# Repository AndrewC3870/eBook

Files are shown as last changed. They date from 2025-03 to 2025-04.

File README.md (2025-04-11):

# OpenBook
Fully functional E-book reader project!
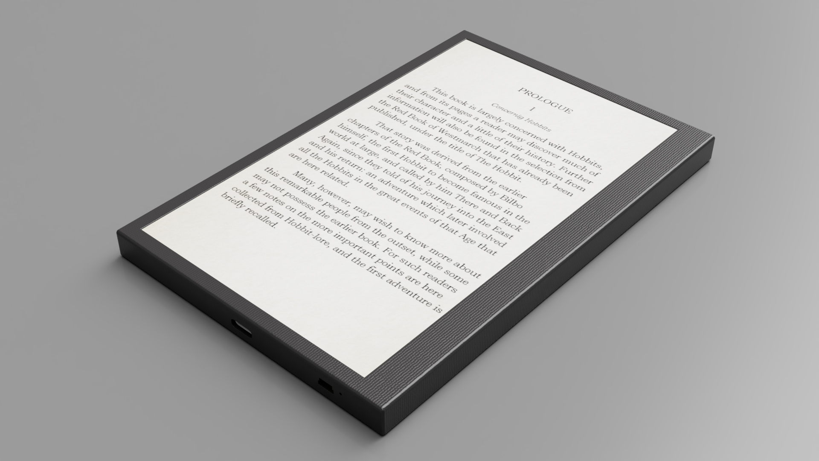
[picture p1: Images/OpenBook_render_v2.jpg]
OpenBook_render_img

## 🧾 Bill of Materials (BOM)

| Component | Link to buy | Datasheet |
|---|---|---|
|ESP32-C6 | [Mouser](https://ro.mouser.com/ProductDetail/Espressif-Systems/ESP32-C6-WROOM-1-N8?qs=8Wlm6%252BaMh8ST02Gmwp74cw%3D%3D) | [Datasheet](https://ro.mouser.com/datasheet/2/891/Espressif_ESP32_C6_WROOM_1__Datasheet_V0_1_PRELIMI-3239987.pdf)|
| E-Ink Display 7.5" 800x480 | [Waveshare](https://www.waveshare.com/7.5inch-e-paper.htm) | [Datasheet](https://files.waveshare.com/upload/6/60/7.5inch_e-Paper_V2_Specification.pdf) |
| SD Module | [Comet](https://store.comet.srl.ro/Catalogue/Product/43497/) | [Datasheet](https://store.comet.bg/download-file.php?id=8824)|
| Polymer Lithium-Ion Battery | [TME](https://www.tme.eu/en/details/accu-lp584174_cl/rechargeable-batteries/cellevia-batteries/l584174/) | [Datasheet](https://www.tme.eu/Document/e0683d8c34e6d878124489f71bffb6ee/cel0014.pdf)|
| RTC DS3231SN  | [Mouser](https://ro.mouser.com/ProductDetail/Analog-Devices-Maxim-Integrated/DS3231SN?qs=1eQvB6Dk1vhUlr8%2FOrV0Fw%3D%3D) | [Datasheet](https://ro.mouser.com/datasheet/2/609/DS3231-3421123.pdf)|
| Environmental Sensor BME688 | [Mouser](https://ro.mouser.com/ProductDetail/Bosch-Sensortec/BME688?qs=IS%252B4QmGtzzqQoVDscqwx3A%3D%3D) | [Datasheet](https://ro.mouser.com/datasheet/2/783/bst_bme688_fl000-2307034.pdf)|
| Li-Po Battery Charging Controller | [Mouser](https://ro.mouser.com/ProductDetail/Microchip-Technology/MCP73831T-3ACI-OT?qs=yUQqVecv4quInAWkk8YFWg%3D%3D) | [Datasheet](https://ro.mouser.com/datasheet/2/268/MCP73831_Family_Data_Sheet_DS20001984H-3441711.pdf)|
| LDO Regulator | [Mouser](https://ro.mouser.com/ProductDetail/Torex-Semiconductor/XC6220A331MR-G?qs=AsjdqWjXhJ8ZSWznL1J0gg%3D%3D) | [Datasheet](https://ro.mouser.com/datasheet/2/760/xc6220-3371556.pdf)|
| External NOR Flash (64MB) | [Mouser](https://ro.mouser.com/ProductDetail/Winbond/W25Q512JVEIQ?qs=l7cgNqFNU1jw6svr3at6tA%3D%3D) | [Datasheet](https://ro.mouser.com/datasheet/2/949/Winbond_W25Q512JV_Datasheet-3240039.pdf)|
| USB-C Connector | [Mouser](https://ro.mouser.com/ProductDetail/GCT/USB4110-GF-A?qs=KUoIvG%2F9IlYiZvIXQjyJeA%3D%3D) | [Datasheet](https://ro.mouser.com/datasheet/2/837/GCT_USB4110_Product_Drawing___20k_cycles-3455479.pdf)|
| Buttons (x3)  | [CoolBe](https://www.coolbe.ro/ro/products/5bad89f21436d4015a56b3cd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) | [Datasheet](https://www.coolbe.ro/ro/products/5bad89f21436d4015a56b3cd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)|
| Qwiic | [SPARKFUN](https://www.sparkfun.com/qwiic-jst-connector-smd-4-pin-horizontal.html) | [Datasheet](https://cdn.sparkfun.com/assets/parts/1/2/2/8/9/Qwiic_Connector_Datasheet.pdf)|
| Schottky Diodes | [Mouser](https://ro.mouser.com/ProductDetail/KYOCERA-AVX/SD0805S020S1R0?qs=jCA%252BPfw4LHbpkAoSnwrdjw%3D%3D) | [Datasheet](https://ro.mouser.com/datasheet/2/40/schottky-3165252.pdf)|
|Resistors | [Mouser](https://ro.mouser.com/c/?q=resistor%200402) | [Datasheet](https://ro.mouser.com/c/?q=resistor%200402)|
|USBLC6-2SC6Y | [Digikey](https://www.digikey.ro/ro/products/detail/stmicroelectronics/USBLC6-2SC6Y/2819177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) | [Datasheet](https://www.st.com/content/ccc/resource/technical/document/datasheet/group0/94/15/6c/58/ba/91/46/42/DM00055262/files/DM00055262.pdf/jcr:content/translations/en.DM000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)|
|Transistors | [Mouser](https://ro.mouser.com/ProductDetail/Diodes-Incorporated/DMG2305UX-7?qs=L1DZKBg7t5F%2FNBHrjfxC%252Bg%3D%3D) | [Datasheet](https://www.diodes.com/assets/Datasheets/DMG2305UX.pdf)|
|SMC Diode | [DigiKey](https://www.digikey.ro/ro/products/detail/smc-diode-solutions/MBR0530/16692306) | [Datasheet](https://www.smc-diodes.com/propdf/MBR0530%20N0717%20REV.A.pdf)|
|N-channel MOSFET | [DigiKey](https://www.digikey.ro/ro/products/detail/vishay-siliconix/SI1308EDL-T1-GE3/4876435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) | [Datasheet](https://www.vishay.com/docs/63399/si1308edl.pdf)|
|Display Connector | [Mouser](https://ro.mouser.com/ProductDetail/Hirose-Connector/FH34SRJ-24S-0.5SH99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) | [Datasheet](https://ro.mouser.com/datasheet/2/185/FH34SRJ_24S_0_5SH_99__CL0580_1255_6_99_2DDrawing_0-1615044.pdf)|
|Power Inductor | [Mouser](https://ro.mouser.com/ProductDetail/Bourns/SRR4828A-101M?qs=EU6FO9ffTwcw5i9FweW3JA%3D%3D) | [Datasheet](https://ro.mouser.com/datasheet/2/54/srr4828a-1391533.pdf)|

## 📊 Bloc Diagram and PCB

<p align="center">
  
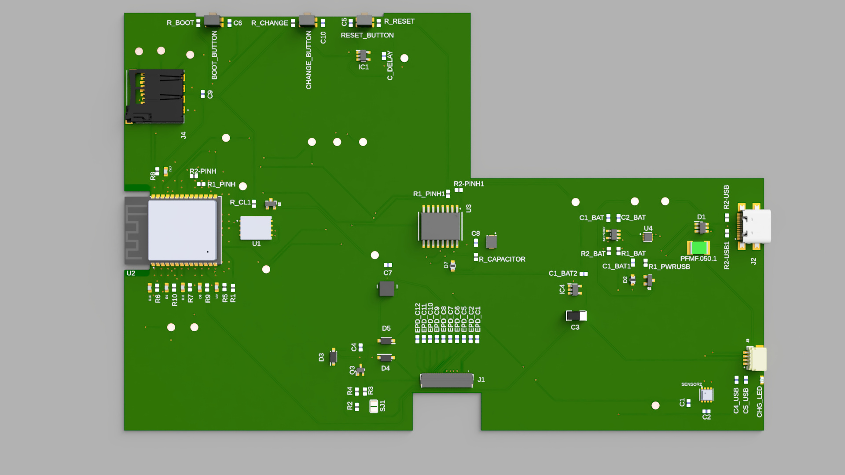
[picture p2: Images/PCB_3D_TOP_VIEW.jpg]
PCB
  
</p>

## 📗 Main Components and Connections
1. **Main processing unit**
    * `ESP32-C6 Microcontroller (ESP32-C6-WROOM-1-N8)` - The central processing unit of the system with WiFi/Bluetooth connectivity.

2. **Power Management System**
    * `LDO Voltage Regulator (XC6220A331MR-G)`: Provides stable 3.3V power from battery/USB

    * `Li-Po Battery Charging Controller (MCP73831)`: Manages charging of the LP584174 battery

    * `Battery Charge Level Monitoring (MAX17048G+T10)`: Connected via I2C to monitor battery status
3. **Display System**
    * `E-Ink Display (7.5" 800×480 px)`: Connected via SPI interface, displays the content

4. **Storage**
    * `External NOR Flash (W25Q512JVEIQ, 64MB)`: Connected via SPI, main memory 64 MB

    * `SD Card`: Connected via SPI, used for external memory extension for adding books

5. **Environmental Sensing**
    * `BME688 Environmental Sensor`: Connected via I2C used to detect a wide variety of volatile organic compounds

6. **Real-Time Clock**
    * `DS3231SN RTC Module`: Connected via I2C (same bus as BME688)measures and tracks time, often in hours, minutes, and seconds

7. **User Interface**
    * `Buttons`: 3x GPIO buttons (Reset, Change, Boot)

8. **Connectivity**
    * `USB-C Connector`: For power and programming
    * `Qwiic/Stemma QT Connector`: I2C expansion port

## 🛠️ ESP32-C6 Used pins

| PIN | Component | Signal Name | Notes|
|-----|---|---|---|
| 3V3 | LDO Voltage Regulator | 3V3 | Supply power |
| EN | Reset Button | RESET| Reset in case of error |
| IO0| RTC Module | INT_RTC | High precision real time clock chip|
| IO1| RTC Module | 32KHZ| High precision real time clock chip|
| IO2| External NOR Flash, SD Card | MISO| Master In Slave Out|
| IO3| E-Paper Display | EPD_BUSY||
| IO4| SD Card | SS_SD | Extern memory (Micro SD cards)|
| IO5| E-Paper Display| EPD_DC||
| IO6| External NOR Flash, SD Card, E-Paper Display| SCK| SCK is the clock line for SPI communication|
| IO7| External NOR Flash, SD Card, E-Paper Display| MOSI|  Master Out Slave In|
| IO9| Boot Button | IO/BOOT| Boot|
| IO10| E-Paper Display | EPD_CS| for E-Ink display|
| IO11| External NOR Flash | FLASH_CS| |
| IO12| ESD protection | USB_D-| Protection against electrostatic discharges |
| IO13| ESD protection | USB_D+| Protection against electrostatic discharges |
| IO14| Change Button | IO/CHANGE| |
| IO15| Test Pads| TX| Transmit data|
| IO16| Test Pads | RX| Receive data|
| IO17| RTC Module | RTC_RST| |
| IO18| Environmental Sensor | I2C_PW|  To detect a wide variety of volatile organic compounds|
| IO19| EPD Power | EPD_3V3_C| Electronic power design|
| IO20| RTC Module, Qwiic / Stemma QT, Battery ChargeLevel| SDA| Transmit data to or from target devices|
| IO21| Battery ChargeLevel, Environmental Sensor, RTC Module, Qwiic / Stemma QT| SCL| Used to synchronously clock data in or out of the target device|
| IO22| E-Paper Display| EPD_RST| |
| GND| Ground | GND | Connected to the main ground|

## 🔋 Power Consumption Considerations
The system is designed for low power operation, because the most power consuming components are the screen and the ESP32-C6.

* E-Ink Display: Only consumes power during updates about **0.3mW**
* ESP32-C6: Can enter deep sleep mode **26.85 μW** between operations and the average power consumption during active mode is **78.32 mW**
* Battery 3.7V 1800mAh that is **6.6W** of power

The avarage lifetime of device is about 14-17 days!

## 🔄 Important updates
∘ Updated the 3d model of the case, maked the design more comfortable by adding smooth edges and a nice texture for better grip, also modified the interior size of the case to perfectly fit the components inside! 

∘ I have added some necessary files (a picture showing the arrangement of the components in the case, and the F3Z file with the complete design).

∘ In the future, the implementation of software that will allow the use of the eBook is expected.

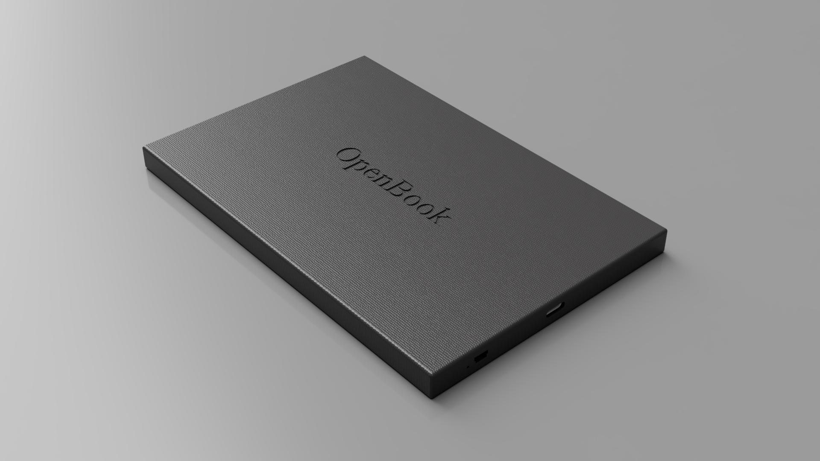
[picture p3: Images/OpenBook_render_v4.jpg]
OpenBook_render_img


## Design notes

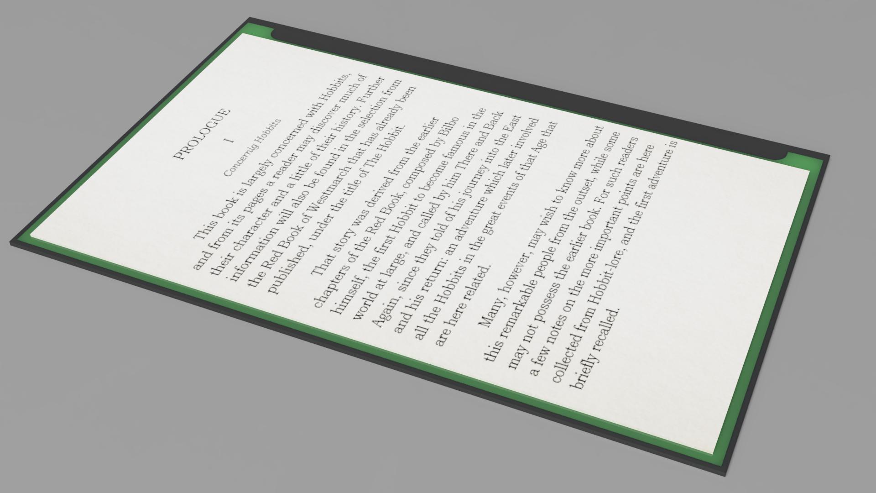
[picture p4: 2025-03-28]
Images/OpenBook_Display.jpg

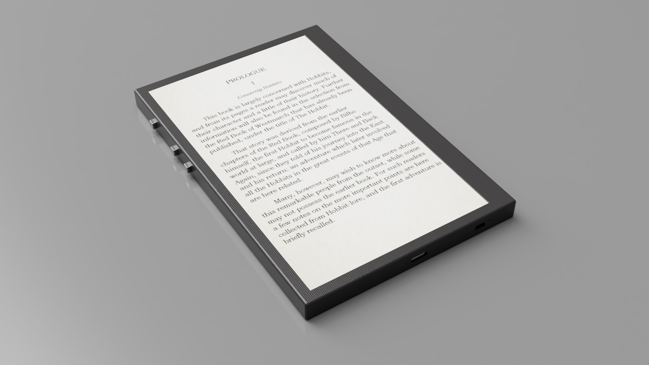
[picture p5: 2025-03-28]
Images/OpenBook_render_v1.jpg

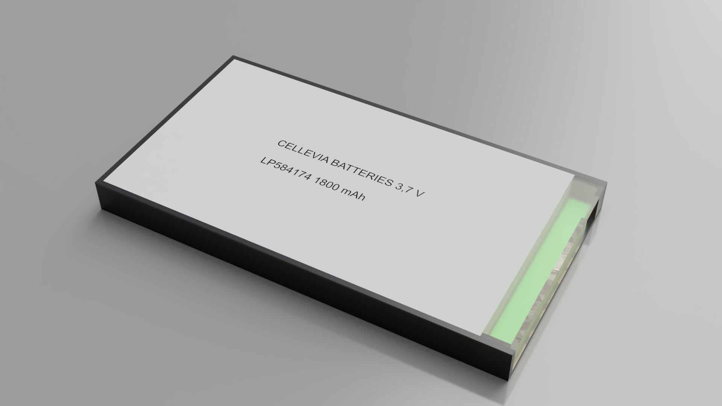
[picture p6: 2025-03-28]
Images/OpenBook_Battery.jpg

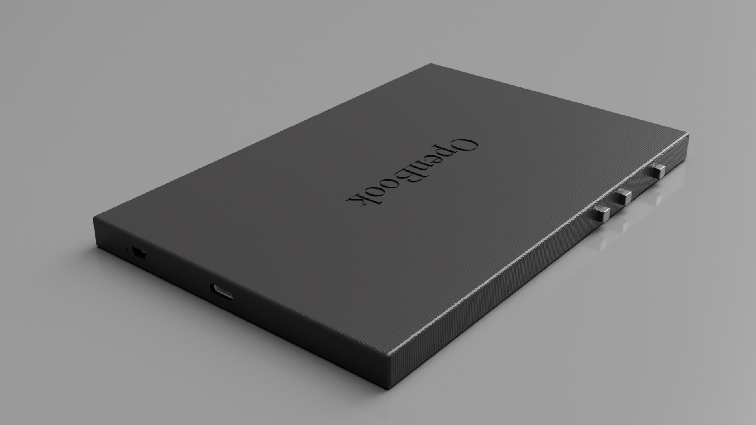
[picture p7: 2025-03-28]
Images/OpenBook_render_v3.jpg

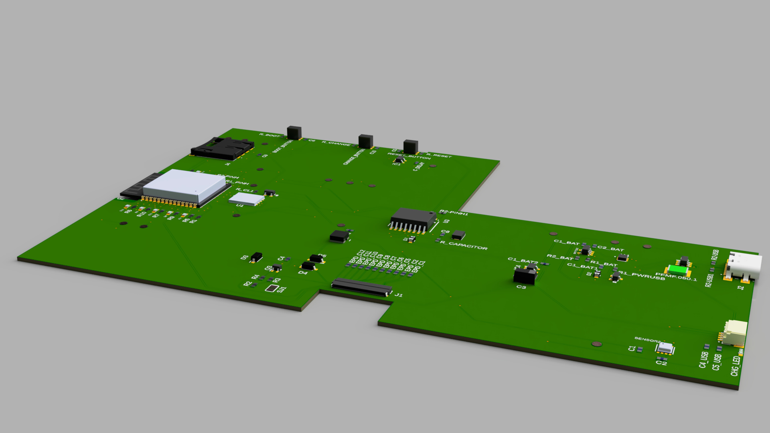
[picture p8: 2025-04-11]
Images/PCB_3D.jpg

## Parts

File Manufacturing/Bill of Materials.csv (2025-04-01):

Qty | Value | Device | Package | Parts | Description
1 |  | ADAFRUIT_LEDCHIP-LED0603 | ADAFRUIT_CHIP-LED0603 | CHG_LED | LED
1 |  | SJ | SJ | SJ1 | SMD solder JUMPER
1 | 0.47 | ESP32_WROVER_EAGLE-LTSPICE_RR0402 | ESP32_WROVER_EAGLE-LTSPICE_R0402 | R3 | RESISTOR, European symbol
1 | 100K | ESP32_WROVER_EAGLE-LTSPICE_RR0402 | ESP32_WROVER_EAGLE-LTSPICE_R0402 | R1_PWRUSB | RESISTOR, European symbol
8 | 100nF | EAGLE-LTSPICE_CC0402 | EAGLE-LTSPICE_C0402 | C1, C2, C4_USB, C6, C8, C9, C10, C_DELAY | CAPACITOR, European symbol
1 | 100uF TANT | RCL_CPOL-EUCT3528 | RCL_CT3528 | C3 | POLARIZED CAPACITOR, European symbol
16 | 10K | ESP32_WROVER_EAGLE-LTSPICE_RR0402 | ESP32_WROVER_EAGLE-LTSPICE_R0402 | R1, R1_PINH, R1_PINH1, R2-PINH, R2-PINH1, R4, R5, R6, R7, R8, R9, R10, R_BOOT, R_CHANGE, R_CL1, R_RESET | RESISTOR, European symbol
1 | 10uF | EAGLE-LTSPICE_CC0402 | EAGLE-LTSPICE_C0402 | C7 | CAPACITOR, European symbol
1 | 112A-TAAR-R03_ATTEND | 112A-TAAR-R03_ATTEND | 112ATAARR03ATTEND | J4 | Micro SD Card Socket, Push-Push Type, Top Mount, SMT, H=1.83mm, 10u
1 | 15 | ESP32_WROVER_EAGLE-LTSPICE_RR0402 | ESP32_WROVER_EAGLE-LTSPICE_R0402 | R_CAPACITOR | RESISTOR, European symbol
1 | 1uF | EAGLE-LTSPICE_CC0402 | EAGLE-LTSPICE_C0402 | C5 | CAPACITOR, European symbol
10 | 1uF/50V | EAGLE-LTSPICE_CC0402 | EAGLE-LTSPICE_C0402 | EPD_C1, EPD_C2, EPD_C5, EPD_C6, EPD_C7, EPD_C8, EPD_C9, EPD_C10, EPD_C11, EPD_C12 | CAPACITOR, European symbol
1 | 2.2 | ESP32_WROVER_EAGLE-LTSPICE_RR0402 | ESP32_WROVER_EAGLE-LTSPICE_R0402 | R2 | RESISTOR, European symbol
1 | 200 | ESP32_WROVER_EAGLE-LTSPICE_RR0402 | ESP32_WROVER_EAGLE-LTSPICE_R0402 | R1_BAT | RESISTOR, European symbol
2 | 20V/4.2A/52mO/1.4W | ESP32_WROVER_SPARKFUN-DISCRETESEMI_MOSFET_PCH-DMG2305UX-7 | ESP32_WROVER_SPARKFUN-DISCRETESEMI_SOT23-3 | Q1, Q2 | P-channel MOSFETs
1 | 2k | ESP32_WROVER_EAGLE-LTSPICE_RR0402 | ESP32_WROVER_EAGLE-LTSPICE_R0402 | R2_BAT | RESISTOR, European symbol
5 | 4.7uF | EAGLE-LTSPICE_CC0402 | EAGLE-LTSPICE_C0402 | C1_BAT, C1_BAT1, C1_BAT2, C2_BAT, C5_USB | CAPACITOR, European symbol
1 | 4.7uF/25V | EAGLE-LTSPICE_CC0402 | EAGLE-LTSPICE_C0402 | C4 | CAPACITOR, European symbol
2 | 5k1 | ESP32_WROVER_EAGLE-LTSPICE_RR0402 | ESP32_WROVER_EAGLE-LTSPICE_R0402 | R2-USB, R2-USB1 | RESISTOR, European symbol
1 | 744043680IND_4828-WE-TPC_WRE | 744043680IND_4828-WE-TPC_WRE | IND_4828-WE-TPC_WRE | L1
1 | BD5229G-TR | BD5229G-TR | SOT95P280X125-5N | IC1 | Voltage Detector with Adjustable Delay Time: CMOS processes are utilized to develop high precision, low current consumption CMOS reset ICs that allow arbitrary setting of the delay time. The extensive lineup includes both Nch Open Drain and CMOS output types in a wide range of detection voltages (from 2.3V to 6.0V, in 0.1V steps), enabling selection of the ideal solution based on customer requirements. In addition, the entire series is of course both lead-free and RoHS-compliant.
3 | BUTTON_CUSYOMV1 | BUTTON_CUSYOMV1 | MYBUTTON | BOOT_BUTTON, CHANGE_BUTTON, RESET_BUTTON
1 | CPH3225A | CPH3225A | CAPCP3225X100N | C10_SUPERCAP | Cap 0.011F 3.3V 1210 Flat Check availability
1 | DS3231SN# | DS3231SN# | SOIC127P1032X265-16N | U3 | Real Time Clock Serial 16-Pin SOIC W T/R Check availability
1 | ESP32-C6-WROOM-1-N8 | ESP32-C6-WROOM-1-N8 | XCVR_ESP32-C6-WROOM-1-N8 | U2 | Check availability
1 | ESP32C6_VARISTORCN1812 | ESP32C6_VARISTORCN1813 | ESP32C6_VARISTOR_CT/CN1812 | PFMF.050.1 | VARISTOR
2 | ESP32_WROVER_AVX---SD0805S020S1R0_AVX_SD0805S020S1R0_0_0AVX_SD0805S020S1R0_0_0 | ESP32_WROVER_AVX---SD0805S020S1R0_AVX_SD0805S020S1R0_0_0AVX_SD0805S020S1R0_0_0 | ESP32_WROVER_AVX---SD0805S020S1R0_AVX_SD0805S020S1R0_0 | D2, D7 | Schottky Barrier Rectifier Diode
1 | ESP32_WROVER_BME680_BME680 | ESP32_WROVER_BME680_BME680 | ESP32_WROVER_BME680_PSON80P300X300X100-8N | SENSOR2 | Integrated Environmental Unit
1 | ESP32_WROVER_SPARKFUN-IC-POWER_MCP73831 | ESP32_WROVER_SPARKFUN-IC-POWER_MCP73831 | ESP32_WROVER_SPARKFUN-IC-POWER_SOT23-5 | MCP73831 | MCP73831T Li-Ion, Li-Pol Controller
1 | FH34SRJ-24S-0.5SH_99_ | FH34SRJ-24S-0.5SH_99_ | FH34SRJ24S05SH99 | J1 | (0.50mm) Surface Mount, Right Angle
1 | MAX17048G+T10 | MAX17048G+T10 | SON50P200X200X80-9N | U4 | Check availability
3 | MBR0530 | MBR0530 | SOD3716X135N | D3, D4, D5 | ON SEMICONDUCTOR - MBR0530 - DIODE, SCHOTTKY, 0.5A, 30V, SOD-123
6 | PGB1010603MR | PGB1010603MR | DIOC1608X36N | D6, D8, D9, D10, D11, D12 | Check availability
1 | QWIIC_RIGHT_ANGLE | QWIIC_CONNECTORJS-1MM | JST04_1MM_RA | J3 | SparkFun I2C Standard Qwiic Connector
1 | SAMACSYS_PARTS_USB4110-GF-A | SAMACSYS_PARTS_USB4110-GF-A | SAMACSYS_PARTS_USB4110GFA | J2 | CONN USB 2.0 TYPE-C R/A SMT
1 | SI1308EDL-T1-GE3 | SI1308EDL-T1-GE3 | SOT65P210X110-3N | Q3 | MOSFET N-Ch 30V 1.5A TrenchFET SC70 Vishay Si1308EDL-T1-GE3 N-channel MOSFET Transistor, 1.5 A, 30 V, 3-Pin SC-70
17 | TPTP20R | TPTP20R | TP20R | TP1, TP2, TP3, TP4, TP5, TP6, TP7, TP8, TP9, TP10, TP11, TP12, TP13, TP14, TP15, TP16, TP17 | Test pad
1 | USBLC6-2SC6Y | USBLC6-2SC6Y | SOT95P280X145-6N | D1 | Low Cap. ESD Protection Auto SOT-23-6 STMicroelectronics USBLC6-2SC6Y, Dual Uni-Directional TVS Diode Array, 6-Pin SOT-23
1 | W25Q512JVEIQ | W25Q512JVEIQ | SON127P600X800X80-9N | U1 | Check availability
1 | XC6220A331MR-G | XC6220A331MR-G | SOT95P280X120-5N | IC4 | LDO Voltage Regulators

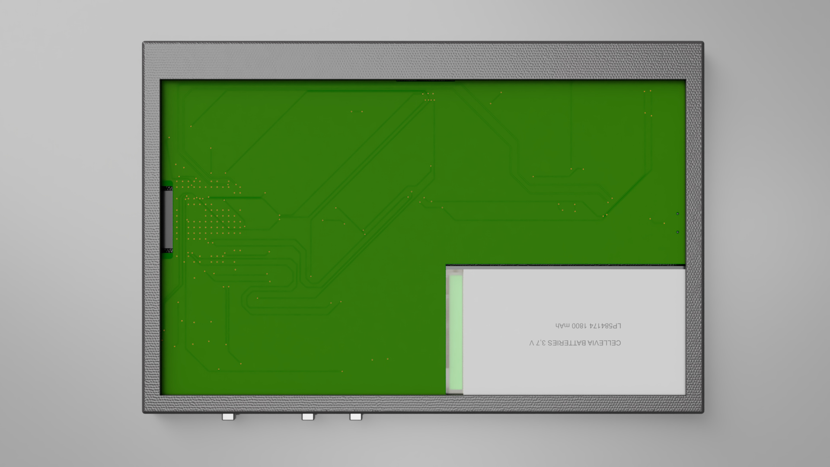
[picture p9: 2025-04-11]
Images/Component_positions.jpg

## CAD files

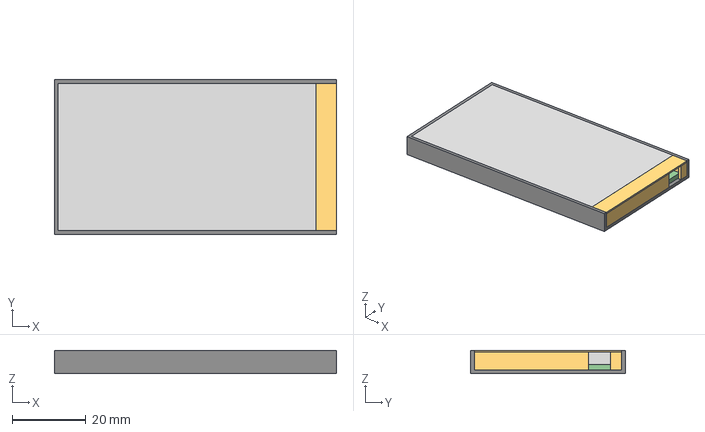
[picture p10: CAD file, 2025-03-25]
Mechanical/Battery_3D v1.step
76.5 x 42.0 x 6.30 mm

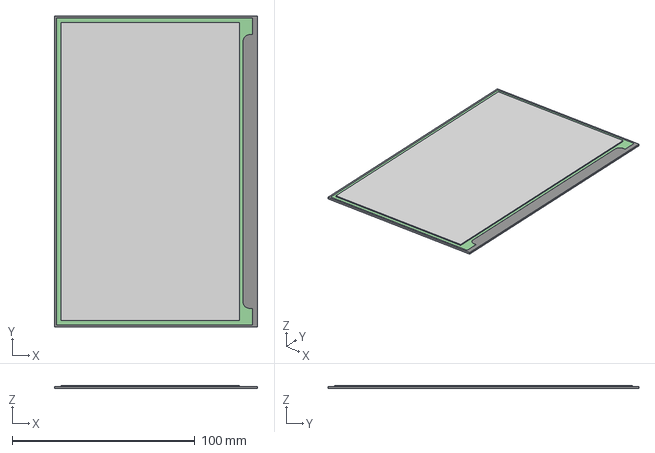
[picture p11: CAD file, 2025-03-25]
Mechanical/E-INK_screen_3D v3.step
111.2 x 170.2 x 1.88 mm

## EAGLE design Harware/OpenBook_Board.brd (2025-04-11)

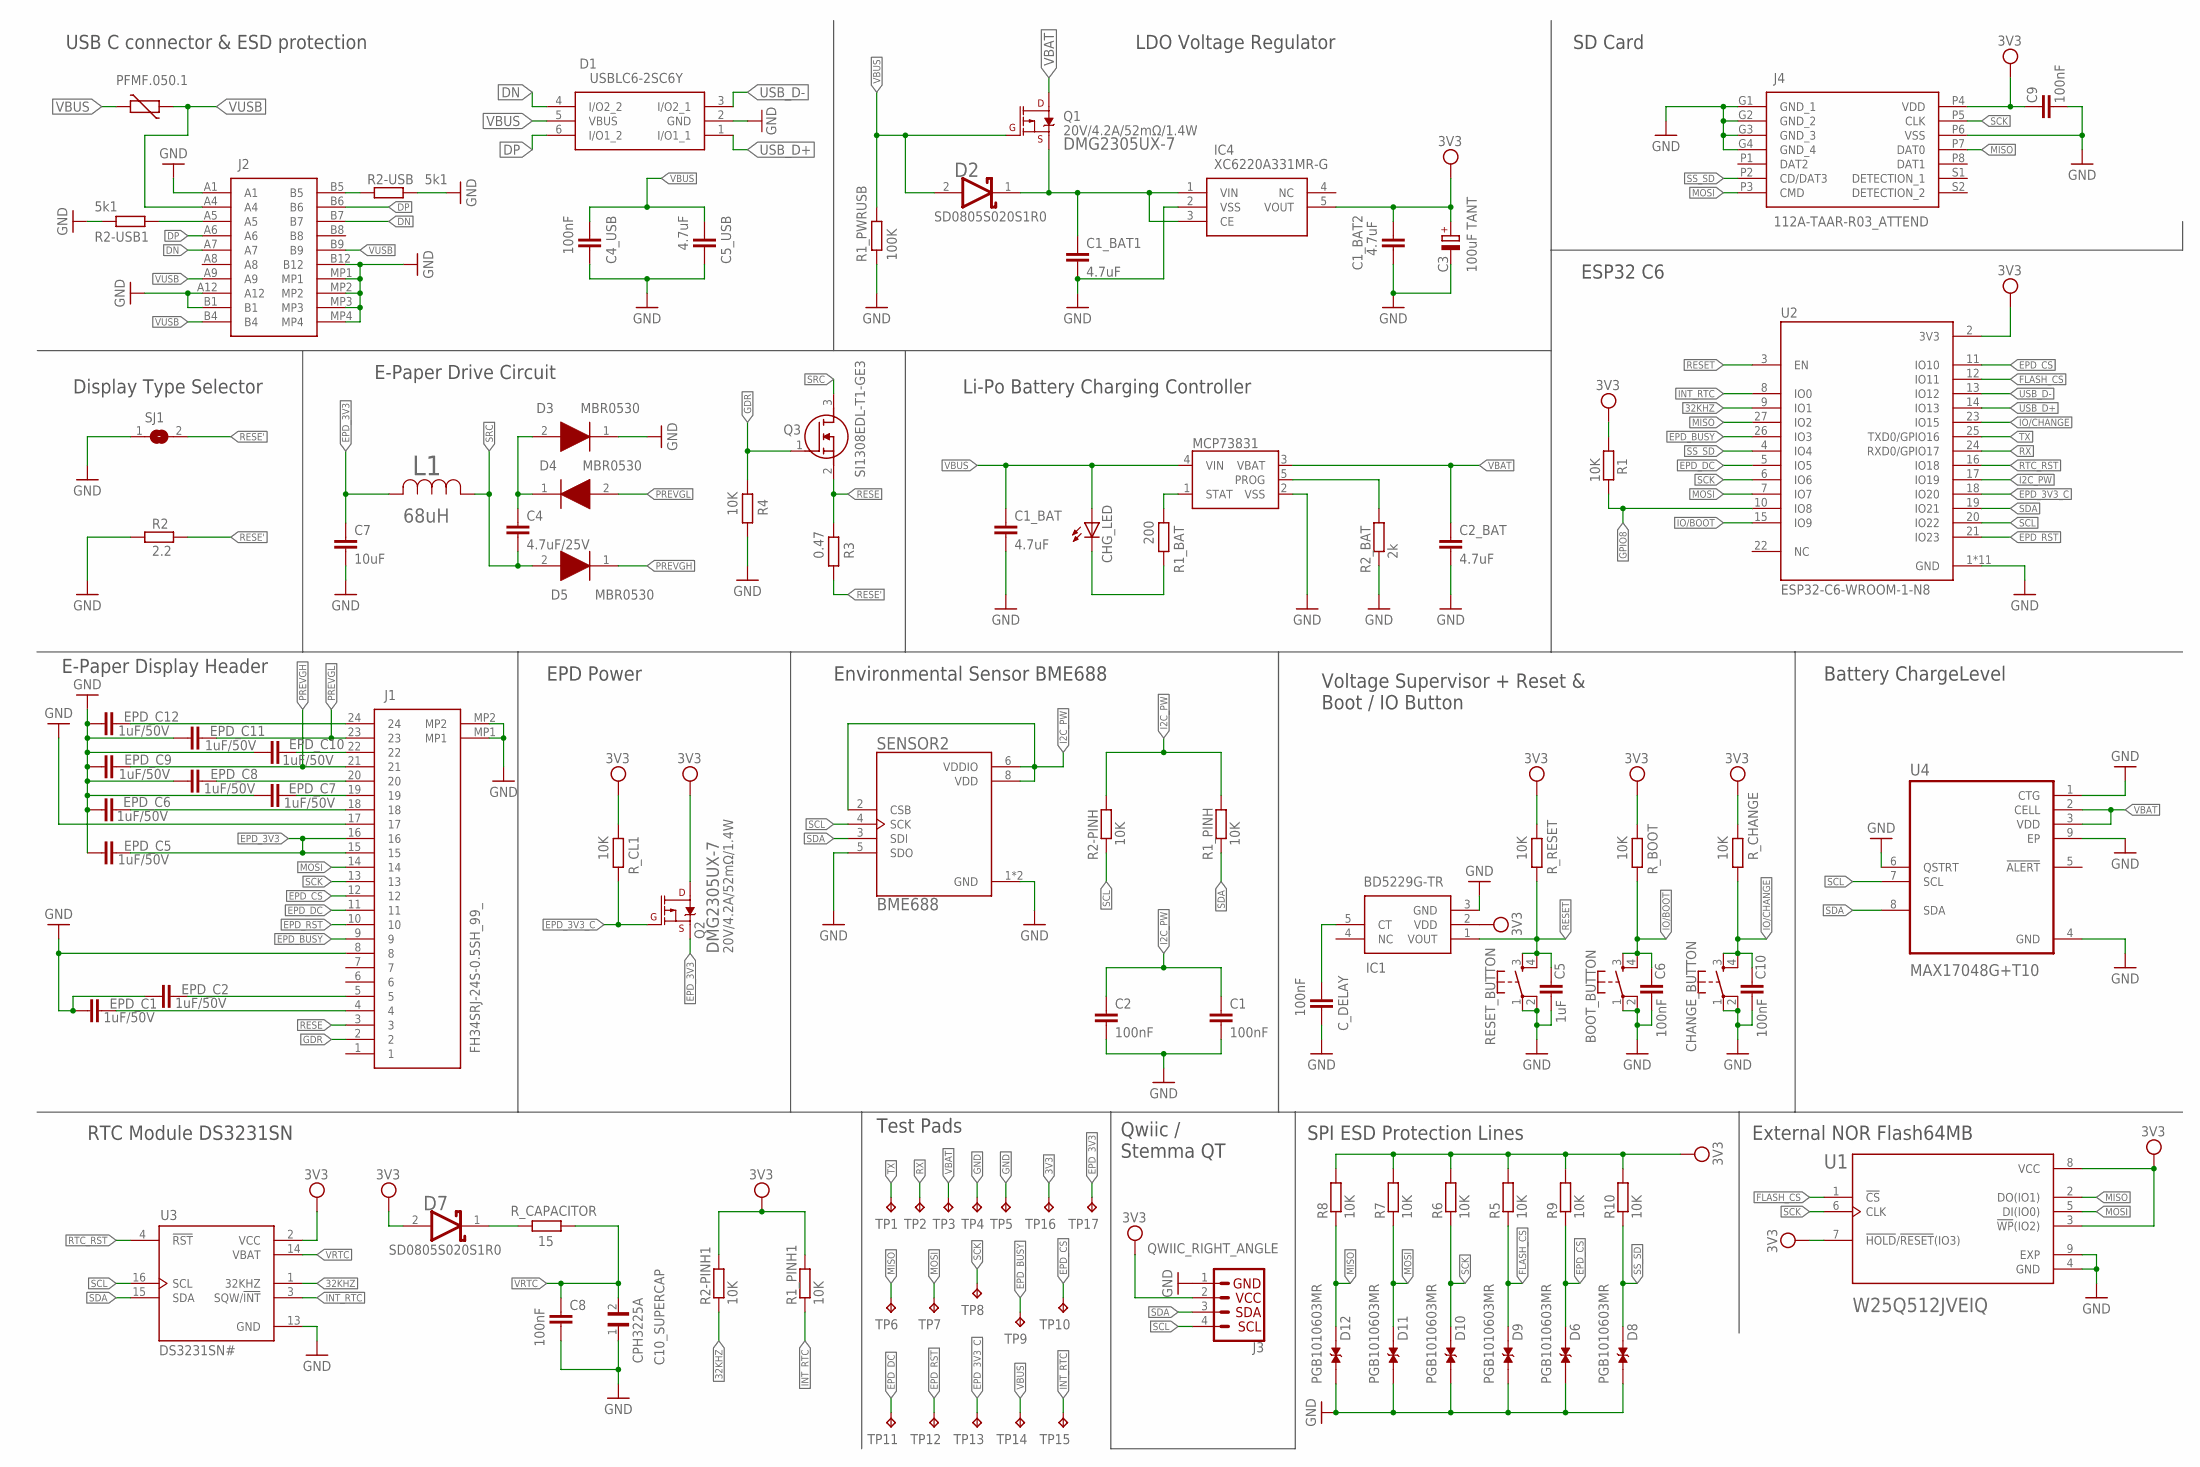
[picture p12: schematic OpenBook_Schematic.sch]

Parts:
BOOT_BUTTON: BUTTON_CUSYOMV1; MYBUTTON
C1, C2, C4_USB, C6, C8, C9, C10: 100nF; EAGLE-LTSPICE_C0402
C1_BAT, C1_BAT1, C1_BAT2, C2_BAT, C5_USB: 4.7uF; EAGLE-LTSPICE_C0402
C3: 100uF TANT; RCL_CT3528
C4: 4.7uF/25V; EAGLE-LTSPICE_C0402
C5: 1uF; EAGLE-LTSPICE_C0402
C7: 10uF; EAGLE-LTSPICE_C0402
C10_SUPERCAP: CPH3225A; CAPCP3225X100N
CHANGE_BUTTON: BUTTON_CUSYOMV1; MYBUTTON
CHG_LED: ADAFRUIT_LEDCHIP-LED0603; ADAFRUIT_CHIP-LED0603
C_DELAY: 100nF; EAGLE-LTSPICE_C0402
D1: USBLC6-2SC6Y; SOT95P280X145-6N
D2, D7: ESP32_WROVER_AVX---SD0805S020S1R0_AVX_SD0805S020S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; ESP32_WROVER_AVX---SD0805S020S1R0_AVX_SD0805S020S1R0_0
D3, D4, D5: MBR0530; SOD3716X135N
D6, D8, D9, D10, D11, D12: PGB1010603MR; DIOC1608X36N
EPD_C1, EPD_C2, EPD_C5, EPD_C6, EPD_C7, EPD_C8, EPD_C9, EPD_C10, EPD_C11, EPD_C12: 1uF/50V; EAGLE-LTSPICE_C0402
IC1: BD5229G-TR; SOT95P280X125-5N
IC4: XC6220A331MR-G; SOT95P280X120-5N
J1: FH34SRJ-24S-0.5SH_99_; FH34SRJ24S05SH99
J2: SAMACSYS_PARTS_USB4110-GF-A; SAMACSYS_PARTS_USB4110GFA
J3: QWIIC_RIGHT_ANGLE; JST04_1MM_RA
J4: 112A-TAAR-R03_ATTEND; 112ATAARR03ATTEND
L1: 744043680IND_4828-WE-TPC_WRE; IND_4828-WE-TPC_WRE
MCP73831: ESP32_WROVER_SPARKFUN-IC-POWER_MCP73831; ESP32_WROVER_SPARKFUN-IC-POWER_SOT23-5
PFMF.050.1: ESP32C6_VARISTORCN1812; ESP32C6_VARISTOR_CT/CN1812
Q1, Q2: 20V/4.2A/52mΩ/1.4W; ESP32_WROVER_SPARKFUN-DISCRETESEMI_SOT23-3
Q3: SI1308EDL-T1-GE3; SOT65P210X110-3N
R1, R1_PINH, R1_PINH1, R2-PINH, R2-PINH1, R4, R5, R6, R7, R8, R9, R10: 10K; ESP32_WROVER_EAGLE-LTSPICE_R0402
R1_BAT: 200; ESP32_WROVER_EAGLE-LTSPICE_R0402
R1_PWRUSB: 100K; ESP32_WROVER_EAGLE-LTSPICE_R0402
R2: 2.2; ESP32_WROVER_EAGLE-LTSPICE_R0402
R2-USB, R2-USB1: 5k1; ESP32_WROVER_EAGLE-LTSPICE_R0402
R2_BAT: 2k; ESP32_WROVER_EAGLE-LTSPICE_R0402
R3: 0.47; ESP32_WROVER_EAGLE-LTSPICE_R0402
RESET_BUTTON: BUTTON_CUSYOMV1; MYBUTTON
R_BOOT: 10K; ESP32_WROVER_EAGLE-LTSPICE_R0402
R_CAPACITOR: 15; ESP32_WROVER_EAGLE-LTSPICE_R0402
R_CHANGE: 10K; ESP32_WROVER_EAGLE-LTSPICE_R0402
R_CL1: 10K; ESP32_WROVER_EAGLE-LTSPICE_R0402
R_RESET: 10K; ESP32_WROVER_EAGLE-LTSPICE_R0402
SENSOR2: ESP32_WROVER_BME680_BME680; ESP32_WROVER_BME680_PSON80P300X300X100-8N
SJ1: SJ
TP1, TP2, TP3, TP4, TP5, TP6, TP7, TP8, TP9, TP10, TP11, TP12, TP13, TP14, TP15, TP16, TP17: TPTP20R; TP20R
U1: W25Q512JVEIQ; SON127P600X800X80-9N
U2: ESP32-C6-WROOM-1-N8; XCVR_ESP32-C6-WROOM-1-N8
U3: DS3231SN#; SOIC127P1032X265-16N
U4: MAX17048G+T10; SON50P200X200X80-9N

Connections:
3V3: C1_BAT2.2, C3.+, C9.2, D7.2 (ANODE), IC1.2 (VDD), IC4.5 (VOUT), J3.2, J4.P4 (VDD), Q2.3 (D), R1.1, R1_PINH1.2, R2-PINH1.2, R5.2, R6.2, R7.2, R8.2, R9.2, R10.2, R_BOOT.2, R_CHANGE.2, R_CL1.2, R_RESET.2, TP16.TP, U1.3 (!WP!(IO2)), U1.7 (!HOLD!/!RESET!(IO3)), U1.8 (VCC), U2.2 (3V3), U3.2 (VCC)
32KHZ: R2-PINH1.1, U2.9 (IO1), U3.1 (32KHZ)
DN: D1.4 (I/O2_2), J2.A7, J2.B7
DP: D1.6 (I/O1_2), J2.A6, J2.B6
EPD_3V3: C7.2, EPD_C5.1, J1.15, J1.16, L1.2, Q2.2 (S), TP17.TP
EPD_3V3_C: Q2.1 (G), R_CL1.1, TP13.TP, U2.18 (IO20)
EPD_BUSY: J1.9, TP9.TP, U2.26 (IO3)
EPD_CS: D6.2, J1.12, R9.1, TP10.TP, U2.11 (IO10)
EPD_DC: J1.11, TP11.TP, U2.5 (IO5)
EPD_RST: J1.10, TP12.TP, U2.21 (IO23)
FLASH_CS: D9.2, R5.1, U1.1 (!CS), U2.12 (IO11)
GDR: J1.2, Q3.1 (G), R4.2
GND: BOOT_BUTTON.1, BOOT_BUTTON.2, C1.1, C1_BAT.1, C1_BAT1.1, C1_BAT2.1, C2.1, C2_BAT.1, C3.-, C4_USB.1, C5.1, C5_USB.1, C6.1, C7.1, C8.2, C9.1, C10.1, C10_SUPERCAP.1, CHANGE_BUTTON.1, CHANGE_BUTTON.2, C_DELAY.1, D1.2 (GND), D3.1 (K), D6.1, D8.1, D9.1, D10.1, D11.1, D12.1, EPD_C1.2, EPD_C2.2, EPD_C5.2, EPD_C6.2, EPD_C7.2, EPD_C8.2, EPD_C9.2, EPD_C10.2, EPD_C11.2, EPD_C12.2, IC1.3 (GND), IC4.2 (VSS), J1.8, J1.17, J1.MP1, J1.MP2, J2.A1, J2.A12, J2.B1, J2.B12, J2.MP1, J2.MP2, J2.MP3, J2.MP4, J3.1, J4.G1 (GND_1), J4.G2 (GND_2), J4.G3 (GND_3), J4.G4 (GND_4), J4.P6 (VSS), MCP73831.2 (VSS), R1_PWRUSB.2, R2.1, R2-USB.2, R2-USB1.1, R2_BAT.1, R4.1, RESET_BUTTON.1, RESET_BUTTON.2, SENSOR2.1 (GND), SENSOR2.5 (SDO), SENSOR2.7 (GND), SJ1.1, TP4.TP, TP5.TP, U1.4 (GND), U1.9 (EXP), U2.1 (GND), U2.28 (GND), U2.29_1 (GND), U2.29_2 (GND), U2.29_3 (GND), U2.29_4 (GND), U2.29_5 (GND), U2.29_6 (GND), U2.29_7 (GND), U2.29_8 (GND), U2.29_9 (GND), U3.13 (GND), U4.1 (CTG), U4.4 (GND), U4.6 (QSTRT), U4.9 (EP)
GPIO8: R1.2, U2.10 (IO8)
I2C_PW: C1.2, C2.2, R1_PINH.2, R2-PINH.2, SENSOR2.2 (CSB), SENSOR2.6 (VDDIO), SENSOR2.8 (VDD), U2.17 (IO19)
INT_RTC: R1_PINH1.1, TP15.TP, U2.8 (IO0), U3.3 (SQW/!INT)
IO/BOOT: BOOT_BUTTON.3, BOOT_BUTTON.4, C6.2, R_BOOT.1, U2.15 (IO9)
IO/CHANGE: C10.2, CHANGE_BUTTON.3, CHANGE_BUTTON.4, R_CHANGE.1, U2.23 (IO15)
MISO: D12.2, J4.P7 (DAT0), R8.1, TP6.TP, U1.2 (DO(IO1)), U2.27 (IO2)
MOSI: D11.2, J1.14, J4.P3 (CMD), R7.1, TP7.TP, U1.5 (DI(IO0)), U2.7 (IO7)
unnamed: J2.A5, R2-USB1.2
unnamed: J2.B5, R2-USB.1
unnamed: C1_BAT1.2, D2.1 (CATHODE), IC4.1 (VIN), IC4.3 (CE), Q1.2 (S)
unnamed: C4.2, D3.2 (A), D4.1 (K)
unnamed: CHG_LED.C, R1_BAT.1
unnamed: MCP73831.1 (STAT), R1_BAT.2
unnamed: MCP73831.5 (PROG), R2_BAT.2
unnamed: EPD_C12.1, J1.24
unnamed: C_DELAY.2, IC1.5 (CT)
unnamed: EPD_C2.1, J1.5
unnamed: EPD_C10.1, J1.22
unnamed: EPD_C8.1, J1.20
unnamed: EPD_C7.1, J1.19
unnamed: EPD_C6.1, J1.18
unnamed: EPD_C1.1, J1.4
unnamed: D7.1 (CATHODE), R_CAPACITOR.2
PREVGH: D5.1 (K), EPD_C9.1, J1.21
PREVGL: D4.2 (A), EPD_C11.1, J1.23
RESE: J1.3, Q3.2 (S), R3.2
RESE': R2.2, R3.1, SJ1.2
RESET: C5.2, IC1.1 (VOUT), RESET_BUTTON.3, RESET_BUTTON.4, R_RESET.1, U2.3 (EN)
RTC_RST: U2.16 (IO18), U3.4 (!RST)
RX: TP2.TP, U2.24 (RXD0/GPIO17)
SCK: D10.2, J1.13, J4.P5 (CLK), R6.1, TP8.TP, U1.6 (CLK), U2.6 (IO6)
SCL: J3.4, R2-PINH.1, SENSOR2.4 (SCK), U2.20 (IO22), U3.16 (SCL), U4.7 (SCL)
SDA: J3.3, R1_PINH.1, SENSOR2.3 (SDI), U2.19 (IO21), U3.15 (SDA), U4.8 (SDA)
SRC: C4.1, D5.2 (A), L1.1, Q3.3 (D)
SS_SD: D8.2, J4.P2 (CD/DAT3), R10.1, U2.4 (IO4)
TX: TP1.TP, U2.25 (TXD0/GPIO16)
USB_D+: D1.1 (I/O1_1), U2.14 (IO13)
USB_D-: D1.3 (I/O2_1), U2.13 (IO12)
VBAT: C2_BAT.2, MCP73831.3 (VBAT), Q1.3 (D), TP3.TP, U4.2 (CELL), U4.3 (VDD)
VBUS: C1_BAT.2, C4_USB.2, C5_USB.2, CHG_LED.A, D1.5 (VBUS), D2.2 (ANODE), MCP73831.4 (VIN), PFMF.050.1.2, Q1.1 (G), R1_PWRUSB.1, TP14.TP
VRTC: C8.1, C10_SUPERCAP.2, R_CAPACITOR.1, U3.14 (VBAT)
VUSB: J2.A4, J2.A9, J2.B4, J2.B9, PFMF.050.1.1

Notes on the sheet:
USB C connector & ESD protection
LDO Voltage Regulator
SD Card
ESP32 C6
Li-Po Battery Charging Controller
E-Paper Display Header
Display Type Selector
E-Paper Drive Circuit
EPD Power
Environmental Sensor BME688
Voltage Supervisor + Reset & Boot / IO Button
Battery ChargeLevel
RTC Module DS3231SN
Test Pads
Qwiic / Stemma QT
SPI ESD Protection Lines
External NOR Flash64MB

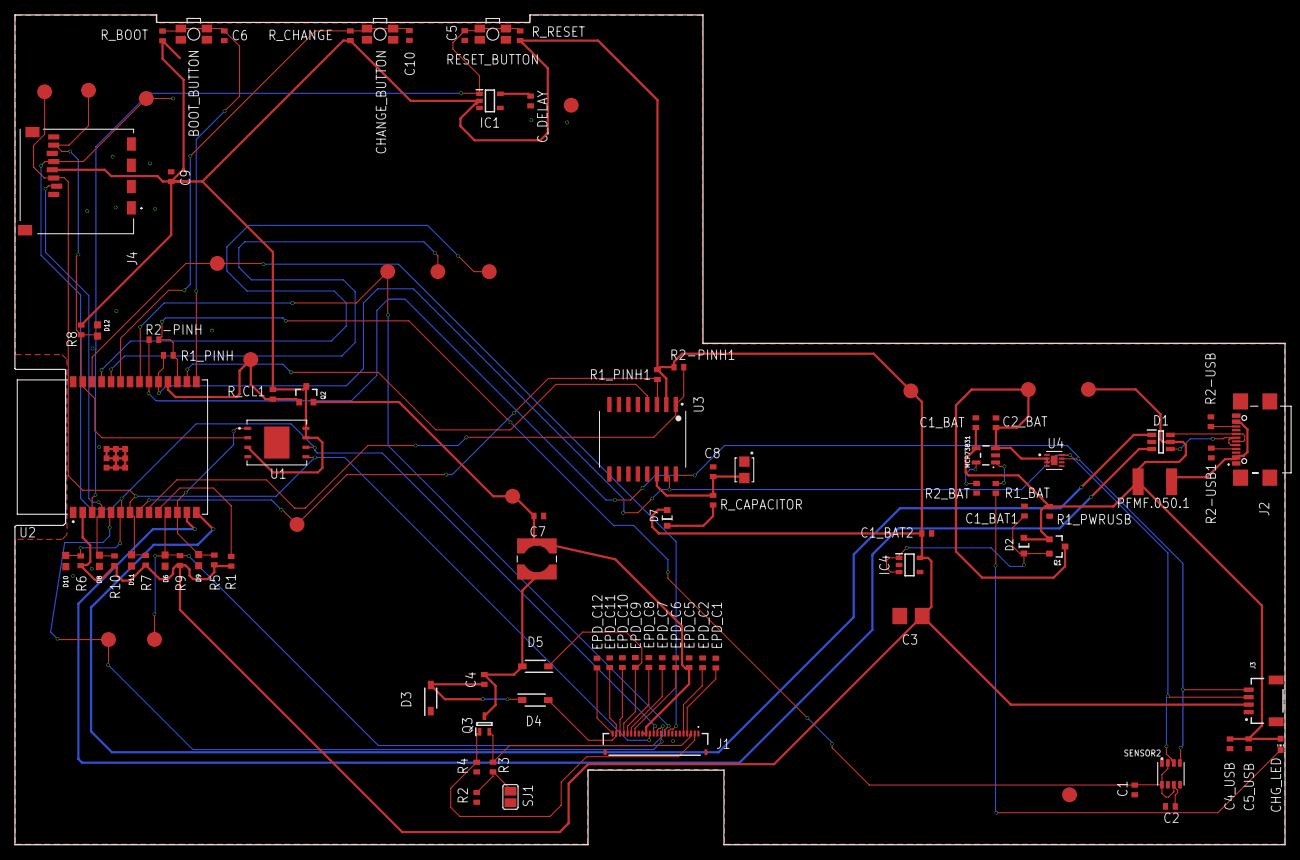
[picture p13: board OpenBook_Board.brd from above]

Board: 2 copper layers, 170.2 x 111.2 mm, 103 parts (0 on the bottom side), 55 nets.

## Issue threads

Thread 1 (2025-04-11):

Mechanical

DucaRaresAndrei, 2025-04-11:
❌ Probleme:

- [x] Lipsa fisier Exploded view
- [x] Lipsa fisier .f3z

✔️ Solutii:

- [x] Schimba Workspace-ul din Design in Animation si trage componentele langa carcasa
- [x] Exporta fisierele in mod corect

📷 Imagine de referinta:

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

Closed 2025-04-11.

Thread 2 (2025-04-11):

PCB design

DucaRaresAndrei, 2025-04-11:
❌ Problema:

- [x] PCB-ul nu este decupat sub antena modulului ESP32

✔️ Solutie:

- [x] Taietura in schema PCB-ului si rezolvarea posibilelor erori de air wire

📷 Poze de referinta:

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

Closed 2025-04-11.

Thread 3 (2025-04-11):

3D Design

DucaRaresAndrei, 2025-04-11:
❌ Problema:

- [x] Placa PCB-ul nu este pozitionata corect in interiorul carcasei: Qwiic, SD card si conectorul Type-C nu se aliniaza corespunzator cu gaurile din carcasa

✔️ Solutie:

- [x] Muta PCB-ul putin mai sus in carcasa

📷 Poze de referinta:

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

AndrewC3870, 2025-04-11:
Deja rezolvata, am uploadat din greseala versiunea veche pe github!!!

Closed 2025-04-11.

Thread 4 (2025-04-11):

Images

DucaRaresAndrei, 2025-04-11:
✔️ Sfat:

- [ ] Ar fi util sa adaugi o imagine din care sa observam toate componentele PCB-ului si bateria, in interiorul carcasei. Asta ajuta in a arata ca toate elementele sunt aranjate corect.

Closed 2025-04-11.

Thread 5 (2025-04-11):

README

DucaRaresAndrei, 2025-04-11:
❌ Problema:

- [ ] Nu ai specificat in Readme procesul de implementare a proiectului.

✔️ Solutie:

- [ ] Poti adauga o scurta descriere a celor mai importanti pasi, in ordinea in care au fost realizati. De altfel, poti mentiona daca a fost nevoie sa accepti anumite warning-uri sau erori, in timpul procesului.

Closed 2025-04-11.

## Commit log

2025-03-23 added sch, brd and 3d model of ebook
    [Board_v24.brd, TSC_Project_v21.sch]
2025-03-25 added the 3d model of battery and screen
    [Battery_3D v1.step, E-INK_screen_3D v3.step]
2025-03-25 updated the images, pcb and 3d designs
    [Board_PCB_v26.brd]
2025-03-25 new PCB image
2025-03-25 fixed issues and updated componets
    [Board_PCB_v26.brd, Board_PCB_v28.brd]
2025-03-28 refactor all the circuit and added renders, step files
    [Board_PCB_v28.brd, OpenBook_Board.brd, OpenBook_Schematic.sch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]
2025-04-01 Added the manufacture
    [Bill of Materials.csv, Pick and Place.csv]
2025-04-06 modified the thicknes of the pcb
2025-04-11 fixed issues
    [OpenBook_Board.brd]

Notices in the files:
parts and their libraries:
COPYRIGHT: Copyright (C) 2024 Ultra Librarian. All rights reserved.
